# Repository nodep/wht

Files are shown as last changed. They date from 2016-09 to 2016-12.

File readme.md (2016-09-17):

This project implements a 3 axis wireless gyro. The hardware consists of two parts: a tracker with sensors and a USB dongle.

The data received from the sensors can be passed to the PC through a USB dongle which enumerates as a joystick and mouse.

The tracker contains these ICs:

- Nordic Semiconductor nRF24LE1 MCU (8-bit 8051)
- InvenSense MPU-6050 (or MPU-9150) IMU (gyro and accelerometer)
- Asahi Kasei AK8975 (magnetometer)

The USB dongle uses a Nordic Semiconductor nRF24LU1+ 2.4GHz and does most of the numerical processing.

There are several variants of the tracker which vary in size and power source. The most practical variant runs off of a single AA battery and has a 3.3V boost regulator (MCP1640). Another variant uses a CR123A lithium battery without a regulator.

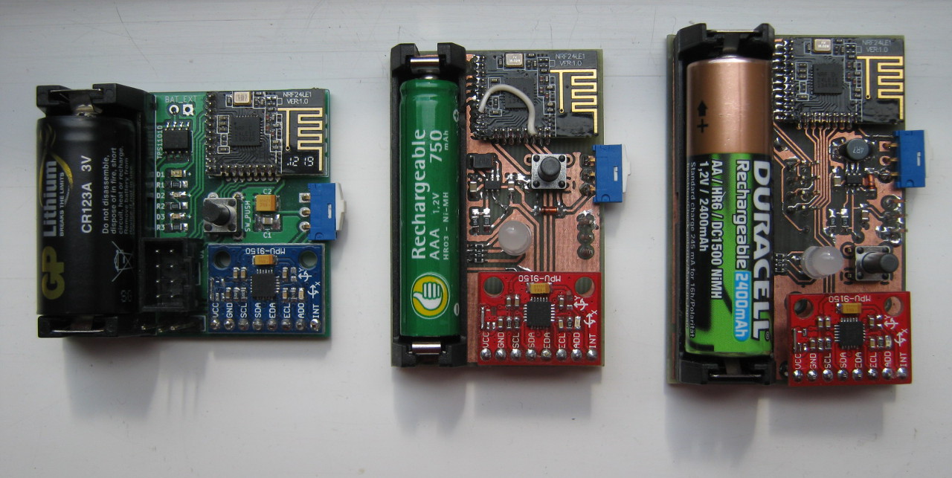
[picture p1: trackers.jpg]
trackers


The tracker is designed around modules (MCU and sensors) which can be easily found on ebay or similar online shops.

The code can be compiled with sdcc (Small Device C Compiler) and flashed to the Nordic nRF chips using nrfburn: https://github.com/nodep/nrfburn

The project contains design files (OpenSCAD and stl) for 3D printed enclosures for the tracker and the dongle.

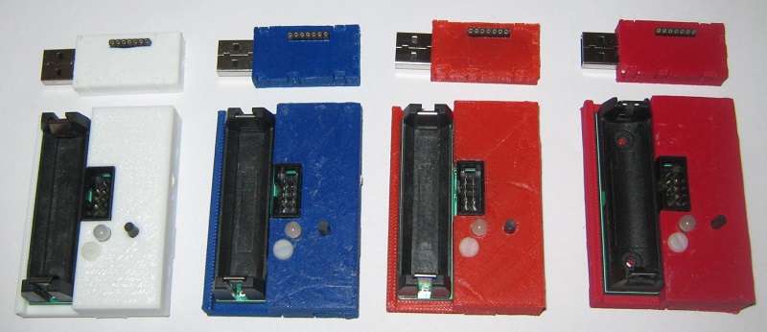
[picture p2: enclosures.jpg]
trackers and dongles in enclosures


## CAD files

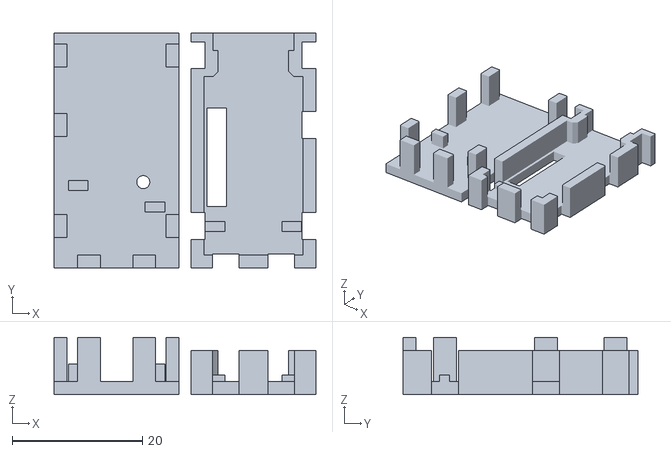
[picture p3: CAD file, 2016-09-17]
enclosure/dongle.stl
40.2 x 36.1 x 8.80

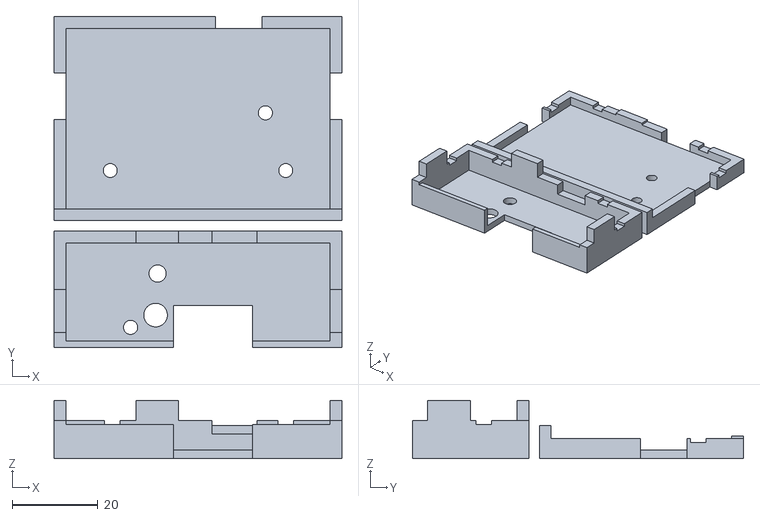
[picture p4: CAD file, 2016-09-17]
enclosure/case_aa.stl
67.1 x 77.2 x 13.6

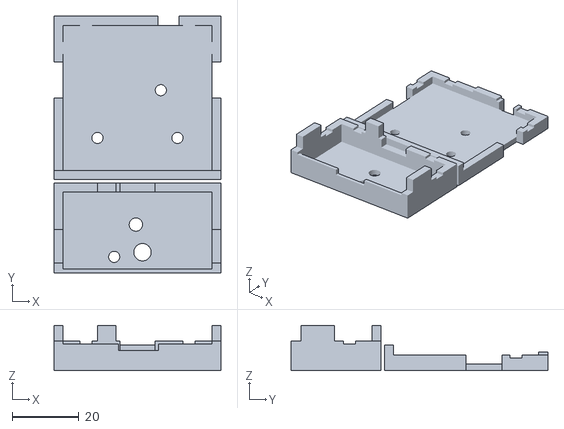
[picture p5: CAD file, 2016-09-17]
enclosure/case_cr123a.stl
50.1 x 77.0 x 13.6

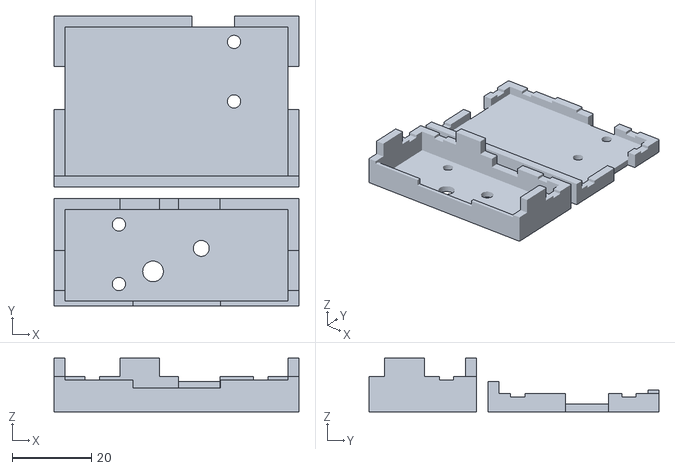
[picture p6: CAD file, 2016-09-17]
enclosure/case_aaa.stl
61.6 x 73.0 x 13.6

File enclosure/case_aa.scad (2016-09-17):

$fn = 80;

include <pcb_aa.scad>

wall_thick_sides = 2.75;
wall_thick_topnbot = 2;
pcb_wiggle = 0.3;
down_room = 1.8;
up_room = 6;
batt_holder_width = 17.4;

switch_x1 = 17;
switch_x2 = 27;
switch_z = 2.1;
switch_wiggle = 0.5;

originx = 35.078;
originy = 104.6385;

module mounting_holes()
{
	// mounting holes
	translate([wall_thick_sides + pcb_wiggle, wall_thick_sides + pcb_wiggle, 0])
	{
		// battery holder holes
		translate([45.128 - originx, originy - 95.9885, -0.1]) cylinder(r = 1.62, h = 25);
		translate([86.028 - originx, originy - 95.9885, -0.1]) cylinder(r = 1.62, h = 25);
		
		// screw hole(s)
		
		// MPU-9150
		//translate([49.20568, 38.84374, -0.1]) cylinder(r = 1.67, h = 25);
		//translate([49.20568, 23.84504, -0.1]) cylinder(r = 1.67, h = 25);
		
		// MPU-6050 + HMC5883L
		translate([82.083 - originx - 0.8, originy - 82.5435, -0.1]) cylinder(r = 1.65, h = 25);
	}
}

module hollow()
{
	translate([wall_thick_sides, wall_thick_sides, wall_thick_topnbot])
		cube([pcbx + pcb_wiggle*2, pcby + pcb_wiggle*2, up_room + down_room + pcb_thick]);
}

module cpegs(wiggle = 0)
{
	cpeg_width = 10;

	cpegy = 24;

	cpeg_height = wall_thick_topnbot + pcb_thick/2 + down_room;

	translate([0, cpegy - wiggle/2, 0])
		cube([wall_thick_sides, cpeg_width + wiggle, cpeg_height]);

	translate([wall_thick_sides + pcbx + pcb_wiggle*2, cpegy - wiggle/2, 0])
		cube([wall_thick_sides, cpeg_width + wiggle, cpeg_height]);

	cpegx = 35;

	translate([wall_thick_sides + pcb_wiggle + cpegx - wiggle/2, wall_thick_sides + pcby + pcb_wiggle*2, 0])
		cube([cpeg_width + wiggle, wall_thick_sides, cpeg_height]);
}

module bottom()
{
	difference()
	{
		union()
		{
			// lower floor
			cube([pcbx + pcb_wiggle*2 + wall_thick_sides*2, pcby + pcb_wiggle*2 + wall_thick_sides*2, pcb_thick/2 + down_room + wall_thick_topnbot]);

			// horizontal battery wall
			translate([0, 0, pcb_thick/2 + down_room + wall_thick_topnbot])
				cube([pcbx + pcb_wiggle*2 + wall_thick_sides*2, wall_thick_sides, 3]);

			// the switch
			translate([wall_thick_sides + pcb_wiggle + switch_x1, wall_thick_sides + pcby + pcb_wiggle*2, pcb_thick/2 + down_room + wall_thick_topnbot])
				cube([switch_x2 - switch_x1, wall_thick_sides, pcb_thick/2 - 0.3]);
		}

		cpegs(0.8);

		hollow();

		translate([wall_thick_sides + pcb_wiggle, wall_thick_sides + pcb_wiggle, wall_thick_topnbot])
			pcb(do_drills = 0, pcb_zoffset = down_room, peg_wiggle = pcb_wiggle, peg_length = wall_thick_sides + 0.5);

		mounting_holes();
	}
}

module top()
{
	// MPU-9150
	//ledx = 76.48;
	//ledy = 80.2545;

	// MPU-6050 or HMC5883L
	ledx = 75.464;
	ledy = 79.683;

	flashx = 62.078 - originx;
	flashy = originy - 82.1385;

	flash_sizex = 18.4;
	flash_sizey = 9.4;

	buttonx = 75;
	buttony = 70;

	inner_wall_thick = 1.5;

	difference()
	{
		translate([0, wall_thick_sides + pcb_wiggle + batt_holder_width, wall_thick_topnbot + pcb_thick/2 + down_room])
			cube([wall_thick_sides*2 + pcbx + pcb_wiggle*2, pcby - batt_holder_width + wall_thick_sides + pcb_wiggle, up_room + pcb_thick/2 + wall_thick_topnbot]);

		// the PCB pegs
		translate([wall_thick_sides + pcb_wiggle, wall_thick_sides + pcb_wiggle, wall_thick_topnbot])
			pcb(do_drills = 0, pcb_zoffset = down_room, peg_wiggle = pcb_wiggle, peg_length = wall_thick_sides + 0.5);

		// the switch
		translate([wall_thick_sides + pcb_wiggle + switch_x1 - switch_wiggle/2, wall_thick_sides + pcb_wiggle*2 + pcby, wall_thick_topnbot + down_room + pcb_thick/2])
			cube([switch_x2 - switch_x1 + switch_wiggle, wall_thick_sides + pcb_wiggle + 0.2, pcb_thick/2 + switch_z + 0.2]);

		hollow();

		mounting_holes();

		// the led hole
		translate([ledx - originx + wall_thick_sides + pcb_wiggle, originy - ledy + wall_thick_sides + pcb_wiggle, wall_thick_topnbot + down_room + pcb_thick + up_room - 0.05])
			cylinder(r = 2.75, h = wall_thick_topnbot + 0.1);

		// the flash connector hole
		translate([flashx - flash_sizex/2 + wall_thick_sides + pcb_wiggle, flashy - flash_sizey/2 + wall_thick_sides + pcb_wiggle - 1, wall_thick_topnbot + down_room + pcb_thick + up_room - 0.05])
			cube([flash_sizex, flash_sizey + 1, wall_thick_topnbot + 0.1]);

		// the recenter button
		translate([buttonx - originx + wall_thick_sides + pcb_wiggle, originy - buttony + wall_thick_sides + pcb_wiggle, 0])
			cylinder(r = 2, h = 20);
	}

	// the inner wall
	translate([wall_thick_sides, wall_thick_sides + pcb_wiggle + batt_holder_width, wall_thick_topnbot + pcb_thick + down_room])
		cube([flashx - flash_sizex/2 + pcb_wiggle, inner_wall_thick, up_room]);

	translate([wall_thick_sides + pcb_wiggle + flashx + flash_sizex/2, wall_thick_sides + pcb_wiggle + batt_holder_width, wall_thick_topnbot + pcb_thick + down_room])
		cube([pcbx - flashx - flash_sizex/2 + pcb_wiggle, inner_wall_thick, up_room]);

	cpegs();
}

bottom();

rotate([0, 180, 0])
	translate([-(wall_thick_sides*2 + pcbx + pcb_wiggle*2), -50, -(wall_thick_topnbot*2 + down_room + up_room + pcb_thick)])
	top();

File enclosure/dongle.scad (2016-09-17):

$fn = 100;

pcbd_thick = 1.1;

// the main part of the dongle PCB
pcbw_x = 14.8;
pcbw_y = 27;

// the neck part of the dongle PCB
pcbn_x = 10.5;
pcbn_y = 4.2;

pcb_zoffset = 0.3;

// USB plug
plug_x = 12.15;
plug_y = 14.8;
plug_z = 5;

// USB plug neck
plugn_x = 9.6;
plugn_y = pcbn_y;
plugn_z = plug_z/2 + pcb_zoffset;

module flash_connector(flash_wigglex = 0, flash_wiggley = 0)
{
	// flashing connector
	flash_sizex = 2.4 + flash_wigglex;
	flash_sizey = 14.6 + flash_wiggley;
	flash_sizez = 5.6 - pcbd_thick;
	flash_posx = 0.6 - flash_wigglex/2;
	flash_posy = 22.1 - flash_sizey + flash_wiggley/2;

	translate([-pcbw_x/2 + flash_posx, flash_posy, -pcbd_thick/2 - flash_sizez])
		cube([flash_sizex, flash_sizey, flash_sizez]);
}

module dongle()
{
	// PCB main PCB
	translate([-pcbw_x/2, 0, -pcbd_thick/2])
		cube([pcbw_x, pcbw_y, pcbd_thick]);

	// PCB neck
	translate([-pcbn_x/2, pcbw_y, -pcbd_thick/2])
		cube([pcbn_x, pcbn_y, pcbd_thick]);

	// USB plug
	translate([-plug_x/2, pcbw_y+pcbn_y, -plug_z/2 + pcbd_thick/2 + pcb_zoffset])
		cube([plug_x, plug_y, plug_z]);
	translate([-plugn_x/2, pcbw_y, pcbd_thick/2])
		cube([plugn_x, plugn_y, plugn_z]);

	flash_connector();
}

pcb_wiggle = 0.4;
wall_thick = 2;

inside_x = pcbw_x + pcb_wiggle;
inside_y = pcbw_y + pcb_wiggle;
inside_z = 4.4 + pcb_wiggle;

module pegs(peg_wiggle = 0.0, thick_wiggle = 0.0)
{
	peg_length = 3.5;
	peg_height = inside_z + wall_thick + peg_wiggle;
	peg_z = -inside_z/2 - wall_thick + pcbd_thick/2 + pcb_zoffset;

	peg_height_flash = inside_z + peg_wiggle;
	peg_z_flash = -inside_z/2 + pcbd_thick/2 + pcb_zoffset;

	// pegs across the length
	peg1_y = 2.5;
	peg2_y = 18;
	peg3_y = 28.7;

	translate([inside_x/2 - thick_wiggle/2, peg1_y - peg_wiggle/2, peg_z])
		cube([wall_thick + thick_wiggle, peg_length + peg_wiggle, peg_height]);

	translate([inside_x/2 - thick_wiggle/2, peg2_y - peg_wiggle/2, peg_z])
		cube([wall_thick + thick_wiggle, peg_length + peg_wiggle, peg_height]);

	translate([inside_x/2 - thick_wiggle/2, peg3_y - peg_wiggle/2, peg_z])
		cube([wall_thick + thick_wiggle, peg_length + peg_wiggle, peg_height]);

	translate([-inside_x/2 - wall_thick - thick_wiggle/2, peg1_y - peg_wiggle/2, peg_z])
		cube([wall_thick + thick_wiggle, peg_length + peg_wiggle, peg_height]);

	translate([-inside_x/2 - wall_thick - thick_wiggle/2, peg3_y - peg_wiggle/2, peg_z])
		cube([wall_thick + thick_wiggle, peg_length + peg_wiggle, peg_height]);

	// pegs across the width
	peg4_x = 2.5;

	translate([peg4_x - peg_wiggle/2, -wall_thick - pcb_wiggle/2 - thick_wiggle/2, peg_z])
		cube([peg_length + peg_wiggle, wall_thick + thick_wiggle, peg_height]);
		
	translate([-peg4_x - peg_length - peg_wiggle/2, -wall_thick - pcb_wiggle/2 - thick_wiggle/2, peg_z])
		cube([peg_length + peg_wiggle, wall_thick + thick_wiggle, peg_height]);
}

case_x = inside_x + wall_thick*2;
case_y = inside_y + wall_thick + pcbn_y + 2.5;
case_z = inside_z + wall_thick*2;

module case_top()
{
	// the LED position
	led_x = 3.3;
	led_y = 11;

	difference()
	{
		translate([-case_x/2, -(pcb_wiggle/2 + wall_thick), inside_z/2 + pcbd_thick/2 + pcb_zoffset])
			cube([case_x, case_y, wall_thick]);

		// the LED hole
		translate([-pcbw_x/2 + led_x, led_y, inside_z/2 + pcbd_thick/2 + pcb_zoffset - 0.1])
			cylinder(wall_thick + 0.2, 1, 1);
	}

	// the stand-offs
	stdoff_thick = 1.5;
	stdoff_height = inside_z/2 + pcb_zoffset;
	stdoff_len = 3;
	stdoff_z = inside_z/2 + pcbd_thick/2 + pcb_zoffset - stdoff_height;

	stdoff1_y = 10.3;
	translate([pcbw_x/2 - stdoff_len, stdoff1_y + pcb_wiggle/2 - stdoff_thick/2, stdoff_z])
		cube([stdoff_len, stdoff_thick, stdoff_height]);

	stdoff3_y = 7;
	translate([-pcbw_x/2, stdoff3_y + pcb_wiggle/2 - stdoff_thick/2, stdoff_z])
		cube([stdoff_len, stdoff_thick, stdoff_height]);

	pegs();
}

module case_bottom(pw = 0.0, ptw = 0.0)
{
	difference()
	{
		translate([-case_x/2, -(pcb_wiggle/2 + wall_thick), -case_z/2 + pcbd_thick/2 + pcb_zoffset])
			cube([case_x, case_y, case_z - wall_thick]);

		translate([-inside_x/2, -pcb_wiggle/2, -inside_z/2 + pcbd_thick/2 + pcb_zoffset])
			cube([inside_x, inside_y, inside_z + 0.1]);

		// wiggle room for the flash connector
		flash_connector(flash_wigglex = 0.6, flash_wiggley = 0.5);

		neck_wigglex = 0.3;
		neck_wigglez = 0.2;

		// PCB and USB neck
		translate([-pcbn_x/2 - neck_wigglex/2, pcbw_y, -plug_z/2 + pcbd_thick/2 + pcb_wiggle])
			cube([pcbn_x + neck_wigglex, pcbn_y, plug_z]);

		// cut-offs for the round edge of the pcb neck
		cutoff = 0.8;
		translate([-pcbn_x/2 - neck_wigglex/2, pcbw_y + pcb_wiggle/2, -plug_z/2 + pcbd_thick/2 + pcb_wiggle])
			linear_extrude(height = plug_z)
				polygon([[0, 0], [-cutoff, 0], [0, cutoff]]);

		translate([pcbn_x/2 + neck_wigglex/2, pcbw_y + pcb_wiggle/2, -plug_z/2 + pcbd_thick/2 + pcb_wiggle])
			linear_extrude(height = plug_z)
				polygon([[0, 0], [cutoff, 0], [0, cutoff]]);
				
		// USB plug
		translate([-plug_x/2 - neck_wigglex/2, pcbw_y + pcbn_y, -plug_z/2 + pcbd_thick/2 + pcb_wiggle])
			cube([plug_x + neck_wigglex, plug_y, plug_z]);

		pegs(peg_wiggle = pw, thick_wiggle = ptw);
	}

	// the stand-offs
	stdoff_thick = 1.5;
	stdoff_height = inside_z/2 - pcb_zoffset - pcbd_thick;
	stdoff_len = 3;

	stdoff1_y = 4;
	translate([pcbw_x/2 - stdoff_len, stdoff1_y + pcb_wiggle/2 - stdoff_thick/2, -pcbd_thick/2 - stdoff_height])
		cube([stdoff_len, stdoff_thick, stdoff_height]);

	translate([-pcbw_x/2, stdoff1_y + pcb_wiggle/2 - stdoff_thick/2, -pcbd_thick/2 - stdoff_height])
		cube([stdoff_len, stdoff_thick, stdoff_height]);
}

translate([0, 0, case_z/2 - pcbd_thick/2 - pcb_zoffset])
	case_bottom(pw = 0.6, ptw = 0.3);

rotate([0, 180, 0])
	translate([21, 0, -case_z/2 - pcbd_thick/2 - pcb_zoffset])
	case_top();

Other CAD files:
enclosure/case_aaa.scad
enclosure/case_cr123a.scad
enclosure/pcb_aa.scad
enclosure/pcb_aaa.scad
enclosure/pcb_cr123a.scad

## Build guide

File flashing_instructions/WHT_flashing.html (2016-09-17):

# Wireless Head Tracker flashing instructions

## Flashing background information

The WHT consists of two separate devices: the first device is the tracker which contains the motion sensor and a microcontroller (just a fancy word for a low power computer) with a 2.4GHz radio transmitter and receiver. The second device is a USB dongle, another microcontroller and another 2.4GHz radio. This USB dongle receives the movement sensor information from the tracker, then processes it and sends it over the USB port to the PC.
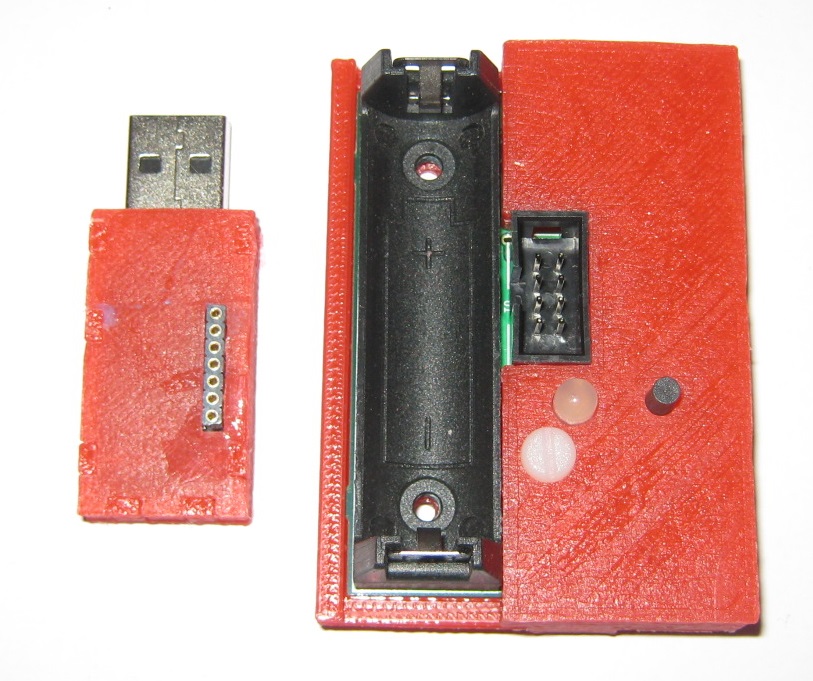
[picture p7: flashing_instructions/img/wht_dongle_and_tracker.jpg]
dongle and tracker


As I've mentioned, the microcontrollers on these two devices are essentially small computers and they contain a little bit of flash memory (16 kilobytes each). This flash memory stores the software these small computers are running. Software running on microcontrollers is often called firmware but in essence it is not much different from software running on your PC or smartphone. And just like any software, the firmware on the tracker and the dongle can be updated to fix bugs or add new features. This update process is called firmware flashing.

In order to flash the two devices, you need to have another device called a flash programmer. It connects to the PC though a USB cable, and to the tracker through a cable, or to the dongle by directly plugging it into the programmer. The programmer receives commands and data from the PC, then sends these commands to the microcontroller on the tracker or dongle which overwrites their flash memory.

The flash programmer with the tracker flashing cable:
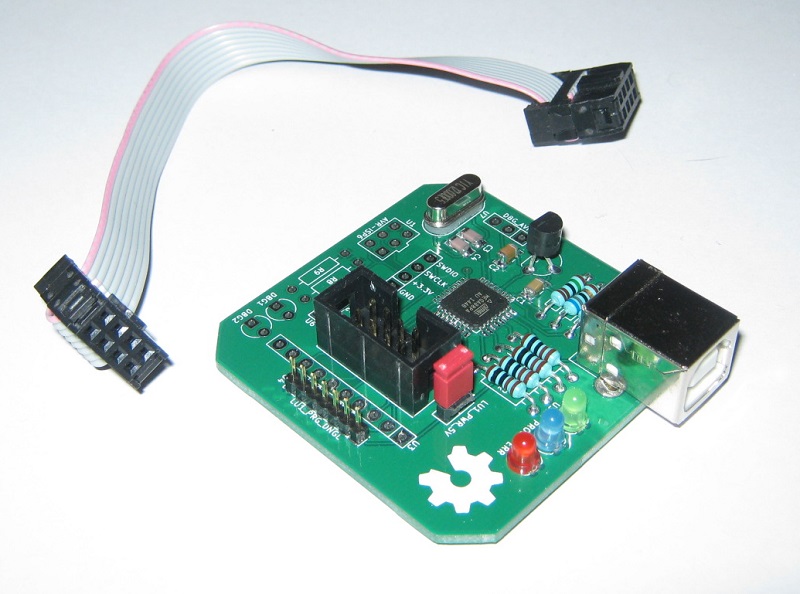
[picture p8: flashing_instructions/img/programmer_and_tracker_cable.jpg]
flash programmer


The flash programmer does not need drivers, but you will need to wait a few minutes after plugging in the programmer for the first time for Windows to figure that out.

## The necessary software

The PC software needed to communicate with the flash programmer, the flash images for the dongle and tracker and the WHT configuration program are all contained in the WHT software package. You will have received it together with this document.

The WHT package has three subfolders:

- config - the configuration and calibration program.
- flashing_instructions - contains these instructions.
- flash - contains the files necessary for the flashing process.

The flash folder contains these files:

- nrfburn.exe - the software which communicates with the flash programmer
- flash_dongle.bat - the windows batch file which calls nrfburn.exe with the required parameters to flash the dongle
- flash_tracker.bat - the windows batch file which calls nrfburn.exe with the required parameters to flash the tracker
- tracker.hex - the tracker flash image
- whtdngl.hex - the dongle flash image

## Tracker flashing details

- Remove the battery from the tracker
- Remove the flash programmer from USB (if it is plugged in)
- If the tracker or the dongle is connected to the flash programmer - remove them
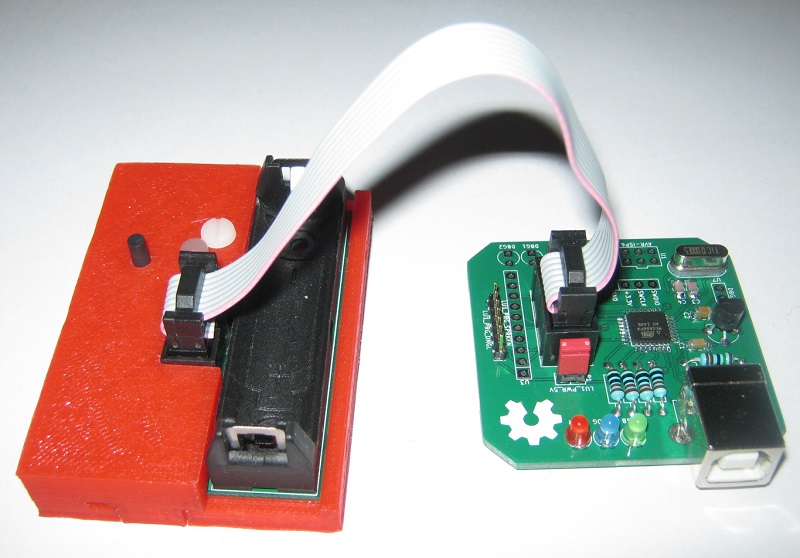
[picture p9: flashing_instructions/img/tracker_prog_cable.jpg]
flasher and tracker
- Plug one end of the flashing cable into the tracker and other into the flash programmer 
- Plug the programmer with the tracker attached into USB. If this is the first time you plugged in the programmer into your PC's USB port, wait a minute or two for Windows to recognize the programmer. You will get a "This device is now ready" message from Windows.
- Go to the folder where you unpacked the WHT software and in the flash subfolder double-click the flash_tracker batch file. The flashing process should take about 6 seconds.
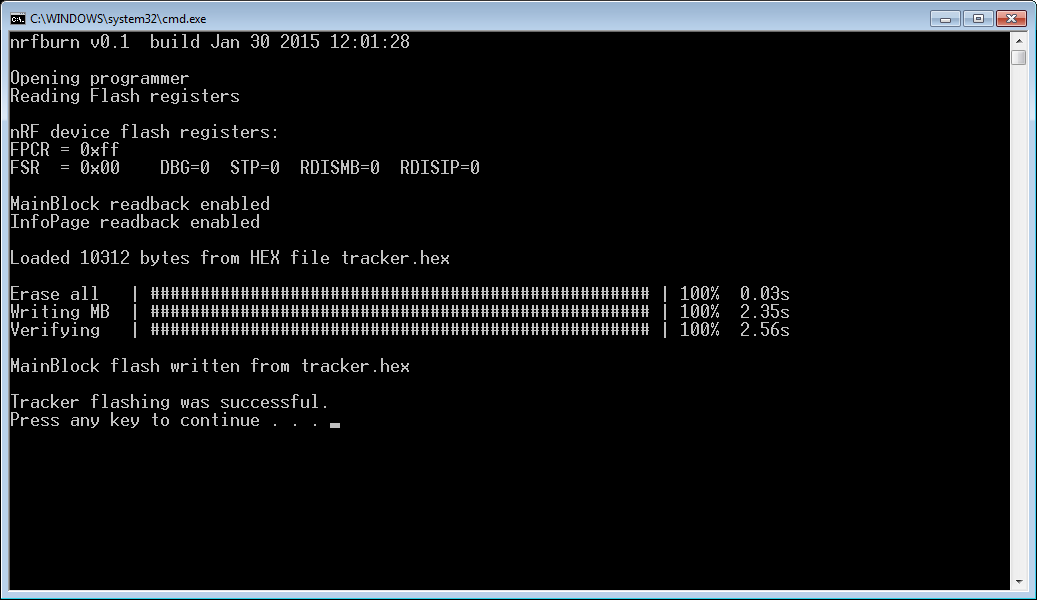
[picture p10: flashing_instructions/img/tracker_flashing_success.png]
tracker flashing
- If the flashing is successful you will see this message in the window: 
- Note that the number of bytes loaded will be different than shown on this image.
- Unplug the flash programmer from USB.
- Remove the programming cable from the programmer and the tracker.
- Put the battery back into the tracker.
- You're done!

## Dongle flashing details

- Remove the flash programmer from USB (if it is plugged in)
- If the tracker or the dongle is connected to the flash programmer - remove them
- Remove the tracker or from the programmer if it is connected to it
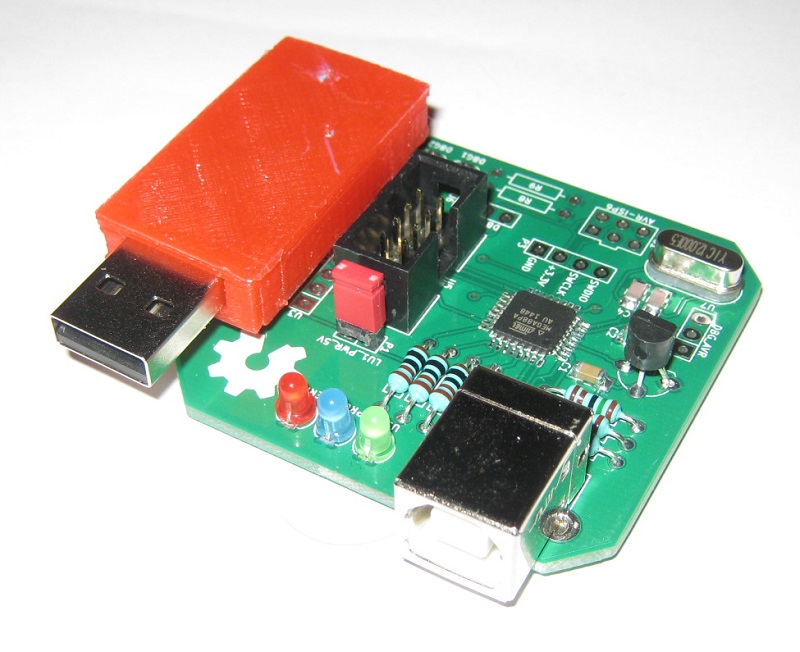
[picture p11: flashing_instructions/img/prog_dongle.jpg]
flashing dongle
- Plug the dongle directly into the programmer's row of pins labelled "LU1+ generic". Make sure that every pin in the programmer is connected to every slot in the dongle. 
- Plug the programmer with the dongle attached into USB. If this is the first time you plugged in the programmer into your PCs USB port, wait a minute or two for Windows to recognize the programmer. You will get a "This device is now ready" message from Windows.
- Go to the folder where you unpacked the WHT software package and run the flash_dongle batch file. The flashing process should take about 6 seconds.
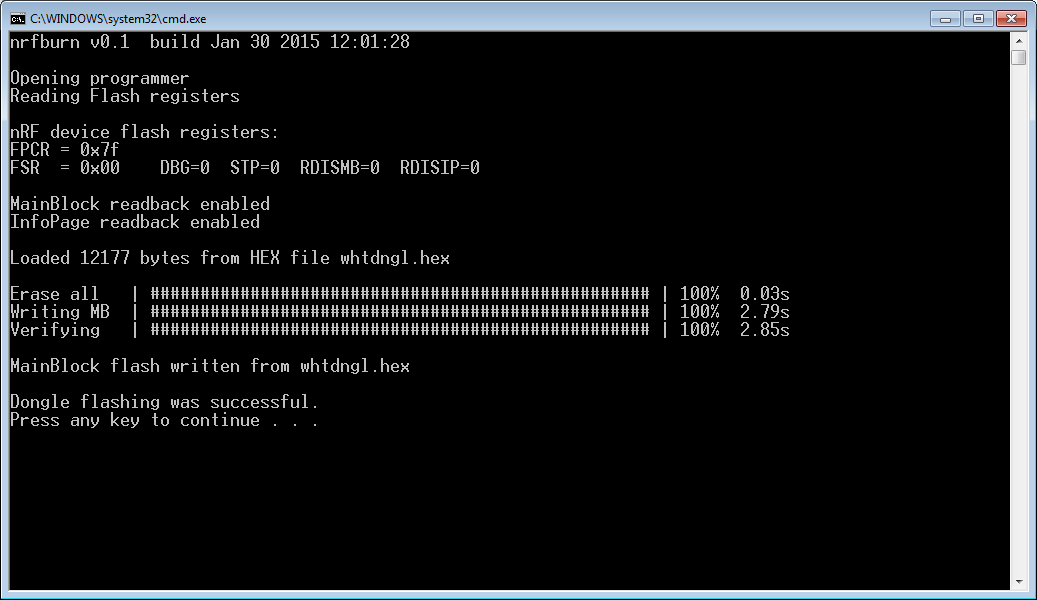
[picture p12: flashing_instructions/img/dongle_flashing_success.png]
dongle flashing
- If the flashing is successful you will see this message in the window: 
- Note that the number of bytes loaded will be different than shown on this image.
- Remove the programmer with the dongle from USB
- Remove the USB dongle from the programmer
- You're done!

After the dongle and tracker have been flashed you will need to recalibrate and reconfigure the devices with the WHTConfig.exe program. You can find the instructions in the video below.

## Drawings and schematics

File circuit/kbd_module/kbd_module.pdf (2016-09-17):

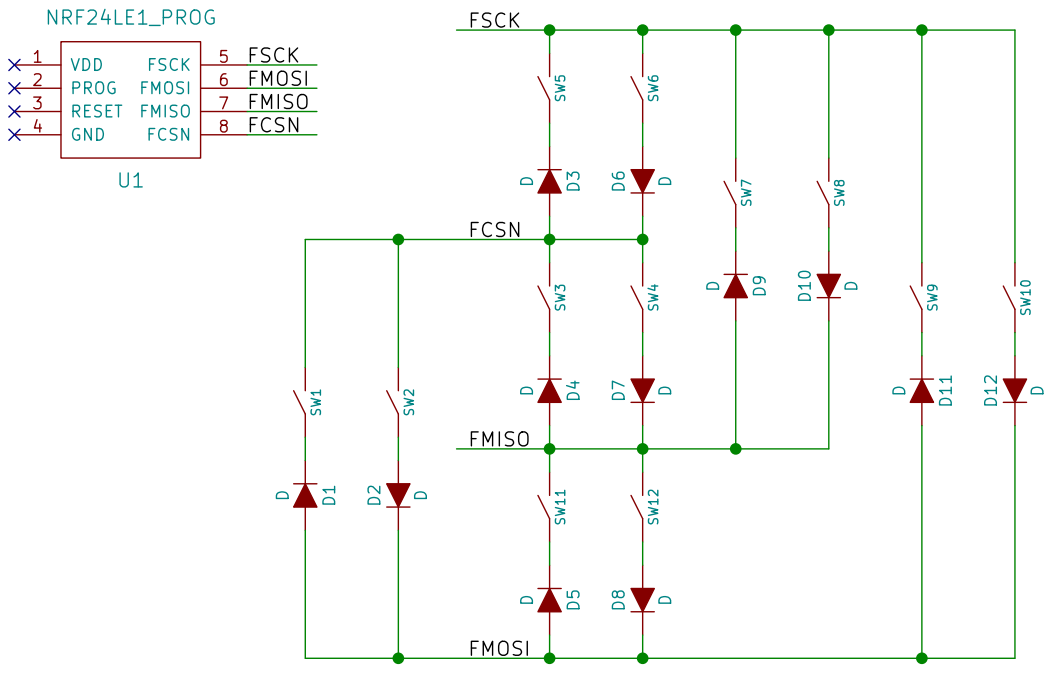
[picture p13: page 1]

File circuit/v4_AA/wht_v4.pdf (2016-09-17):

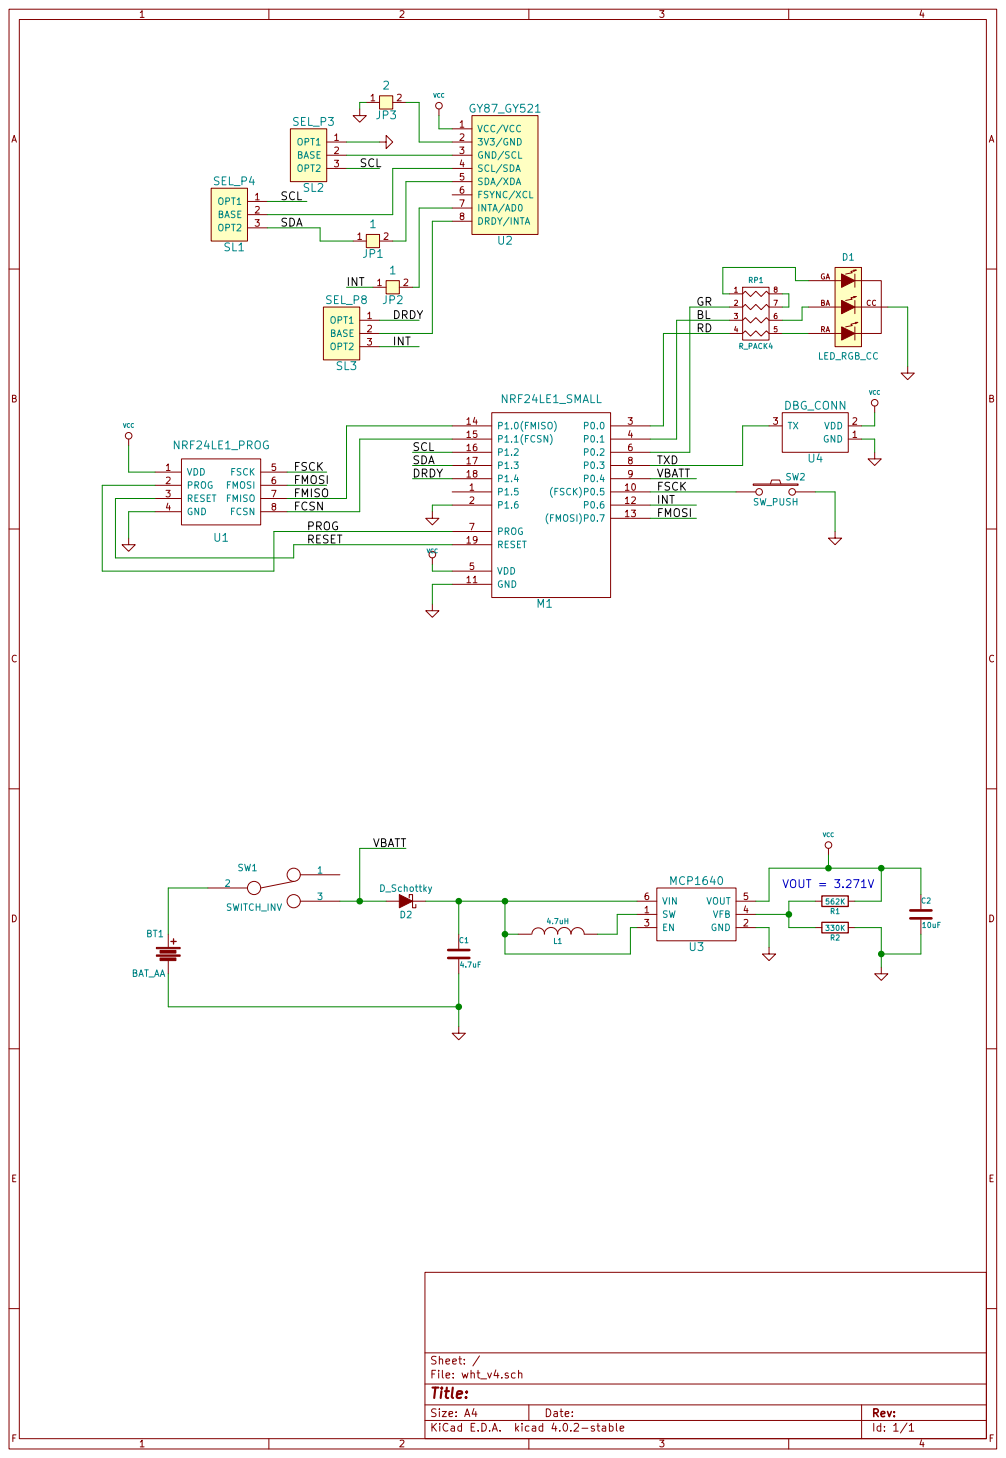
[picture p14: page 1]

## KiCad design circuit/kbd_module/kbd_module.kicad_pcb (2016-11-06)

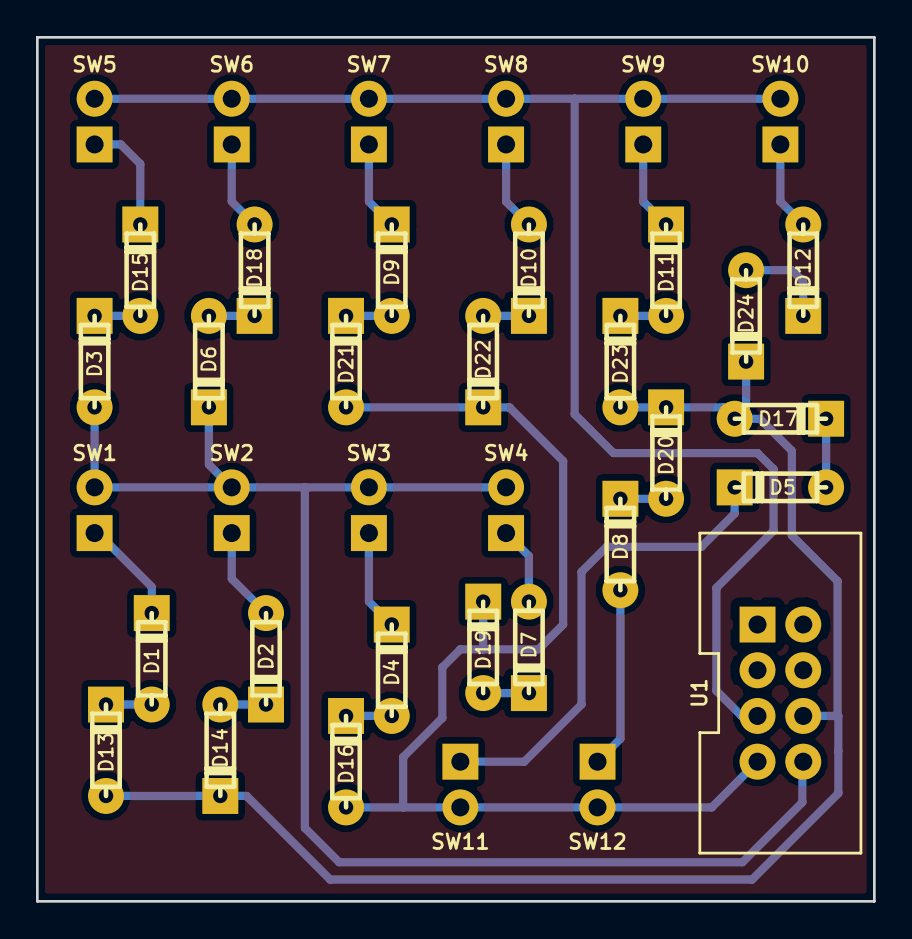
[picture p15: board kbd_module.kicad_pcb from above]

Board: 2 copper layers, 46.5 x 48.0 mm, 37 parts (0 on the bottom side), 28 nets.

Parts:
D1, D2, D3, D4, D5, D6, D7, D8, D9, D10, D11, D12, D13, D14, D15, D16, D17, D18, D19, D20, D21, D22, D23, D24: 1n4148; SOD27_RM5_5
SW1, SW2, SW3, SW4, SW5, SW6, SW7, SW8, SW9, SW10, SW11, SW12: SW_SIMPLE; ExtSwitch
U1: NRF24LE1_PROG; NRF_ICSP_RibbonCable

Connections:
/FCSN: D3.2, D6.1, SW1.2, SW2.2, SW3.2, SW4.2, U1.8
/FMISO: D16.2, D19.1, D21.2, D22.1, SW11.2, SW12.2, U1.7
/FMOSI: D13.2, D14.1, D17.2, D20.1, D23.2, D24.1, U1.6
/FSCK: SW5.2, SW6.2, SW7.2, SW8.2, SW9.2, SW10.2, U1.5
unnamed: D1.1, SW1.1
unnamed: D1.2, D13.1
unnamed: D2.2, SW2.1
unnamed: D4.1, SW3.1
unnamed: D5.1, SW11.1
unnamed: D7.2, SW4.1
unnamed: D8.2, SW12.1
unnamed: D9.1, SW7.1
unnamed: D10.1, D22.2
unnamed: D10.2, SW8.1
unnamed: D11.1, SW9.1
unnamed: D11.2, D23.1
unnamed: D12.1, D24.2
unnamed: D12.2, SW10.1
unnamed: D2.1, D14.2
unnamed: D15.1, SW5.1
unnamed: D3.1, D15.2
unnamed: D4.2, D16.1
unnamed: D5.2, D17.1
unnamed: D6.2, D18.1
unnamed: D18.2, SW6.1
unnamed: D7.1, D19.2
unnamed: D8.1, D20.2
unnamed: D9.2, D21.1

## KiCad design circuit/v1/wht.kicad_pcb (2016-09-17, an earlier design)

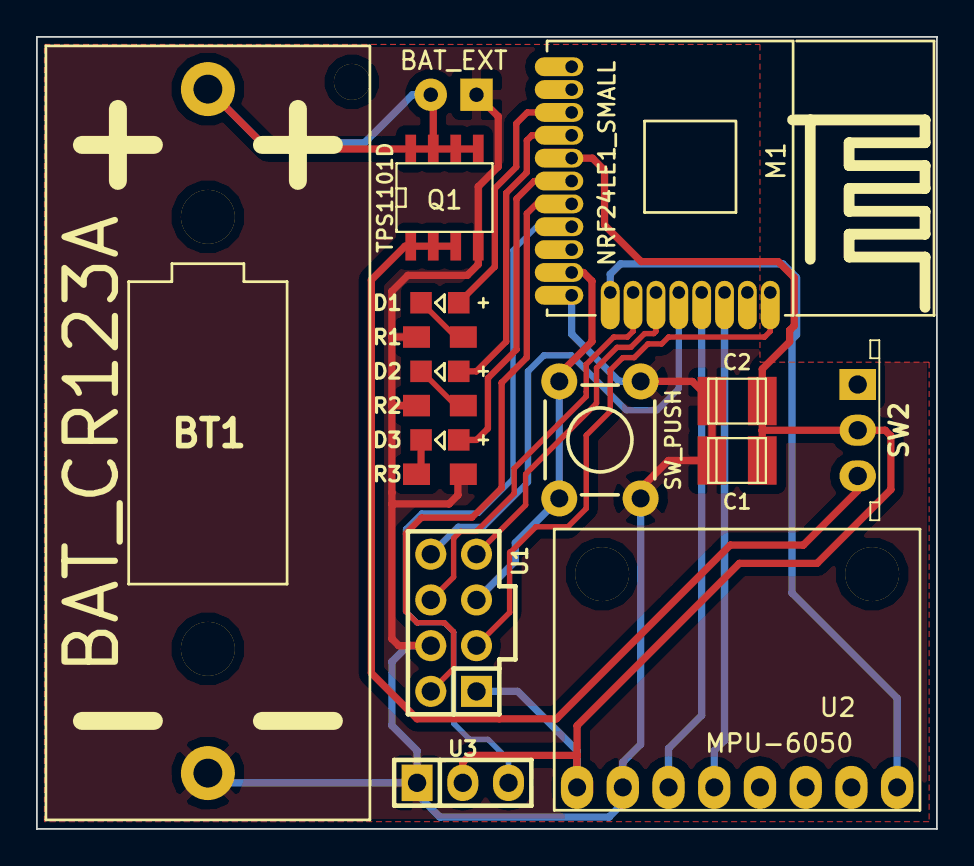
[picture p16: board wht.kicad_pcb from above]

Board: 2 copper layers, 50.0 x 44.0 mm, 17 parts (0 on the bottom side), 20 nets.

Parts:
BT1: BAT_CR123A; CR123
BT2: BAT_EXT; BATTERY_EXT
C1: C; c_1210
C2: CP1; c_1210
D1, D2, D3: LED; LED-0805
M1: NRF24LE1_SMALL
Q1: TPS1101D; SOIC-8_N
R1, R2, R3: R; Resistor_SMD0805_HandSoldering
SW1: SW_PUSH; TACTILE-PTH
SW2: SWITCH_INV; ESP2010_switch
U1: NRF24LE1_PROG; Pin_Header_Straight_2x04
U2: MPU-6050; MPU6050
U3: UART; Pin_Header_Straight_1x03

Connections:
/FCSN: M1.15, U1.8
/FMISO: M1.14, U1.7
/FMOSI: M1.13, U1.6
/FSCK: M1.10, SW1.1, U1.5
/PROG: M1.7, U1.2
/RESET: M1.19, U1.3
/SCL: M1.16, U2.3
/SDA: M1.17, U2.4
GND: BT1.2, BT2.2, C1.2, C2.2, M1.11, Q1.4, R1.1, R2.1, R3.1, SW1.2, U1.4, U2.2, U3.1
unnamed: BT1.1, BT2.1, Q1.5, Q1.6, Q1.7, Q1.8
unnamed: D1.1, M1.3
unnamed: D1.2, R1.2
unnamed: D2.1, M1.4
unnamed: D2.2, R2.2
unnamed: D3.1, M1.6
unnamed: D3.2, R3.2
unnamed: M1.8, U3.3
unnamed: M1.12, U2.8
unnamed: Q1.1, Q1.2, Q1.3, SW2.3
VCC: C1.1, C2.1, M1.5, SW2.2, U1.1, U2.1, U3.2

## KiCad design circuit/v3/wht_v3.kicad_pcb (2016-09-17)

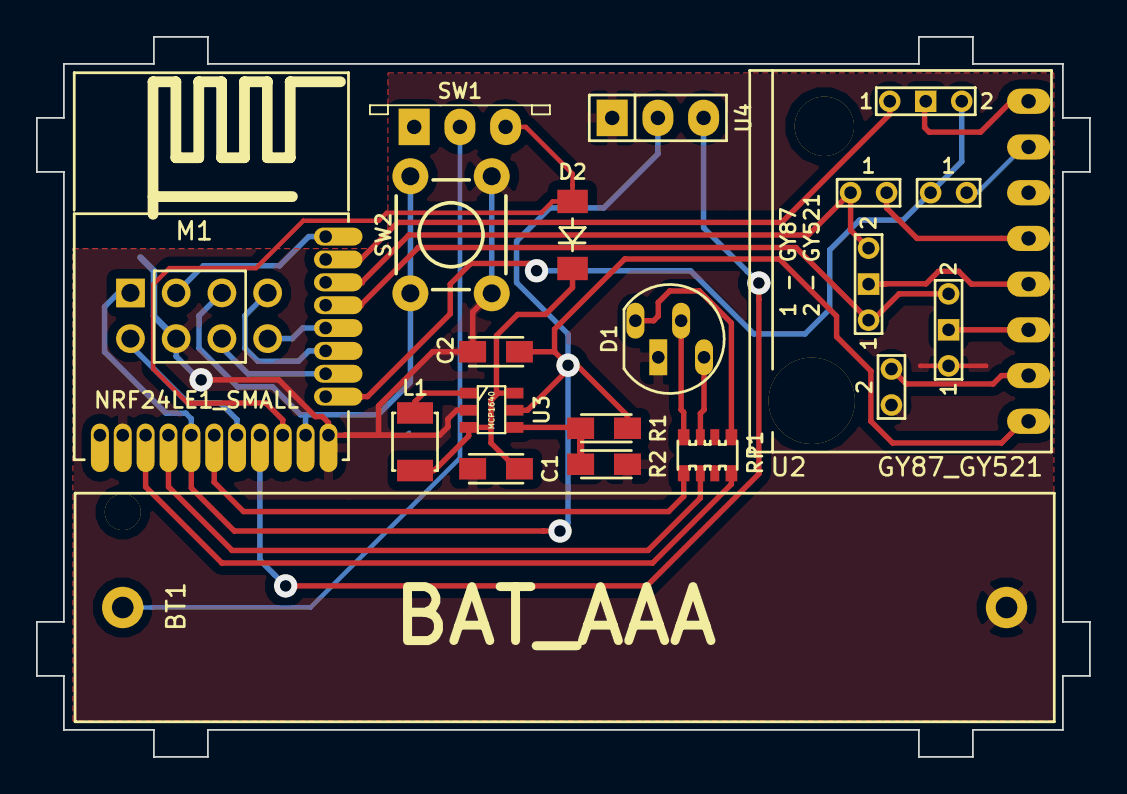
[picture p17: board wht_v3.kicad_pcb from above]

Board: 2 copper layers, 58.5 x 40.0 mm, 22 parts (1 on the bottom side), 30 nets.

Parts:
BT1: BAT_AAA; BATT_HOLDER_AAAx1_KEYSTONE_1021
C1: 4.7uF; Capacitor_SMD0805_HandSoldering
C2: 10uF; Capacitor_SMD0805_HandSoldering
D1: LED_RGB_CC
D2: DIODESCH; Diode-MiniMELF_Handsoldering
JP1, JP2: 1; JumperTHT
JP3: 2; JumperTHT
L1: 4.7uH; INDUCTOR_NLCV25T
M1: NRF24LE1_SMALL
R1: 511K; Resistor_SMD0805_HandSoldering
R2: 348K; Resistor_SMD0805_HandSoldering
RP1: R_PACK4; Resistor_Array_x4_1206
SL1, SL3: SEL_P4; SelectTHT
SL2: SEL_P3; SelectTHT
SW1: SWITCH_INV; ESP2010_switch
SW2: SW_PUSH; TACTILE-PTH
U1: NRF24LE1_PROG; NRF_ICSP_PogoPinsHoles
U2: GY87_GY521
U3: MCP1640; SOT23_6_WHT
U4: DBG_CONN; Pin_Header_Straight_1x03

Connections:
/DRDY: M1.18, SL3.1
/FCSN: M1.15, U1.8
/FMISO: M1.14, U1.7
/FMOSI: M1.13, U1.6
/FSCK: M1.10, SW2.1, U1.5
/GR: M1.6, RP1.1
/INT: JP1.1, M1.12, SL3.3
/PROG: M1.7, U1.2
/RD: M1.3, RP1.4
/RESET: M1.19, U1.3
/SCL: M1.16, SL1.1, SL2.3
/SDA: JP2.1, M1.17, SL1.3
/TXD: M1.8, U4.3
/VBATT: D2.1, M1.9, SW1.3
/YL: M1.4, RP1.2
GND: BT1.2, C1.2, C2.2, D1.CC, JP3.1, M1.2, M1.11, R2.1, SL2.1, SW2.2, U1.4, U3.2, U4.1
unnamed: BT1.1, SW1.2
unnamed: C1.1, D2.2, L1.1, U3.3, U3.6
unnamed: D1.BA, RP1.7
unnamed: D1.GA, RP1.8
unnamed: D1.RA, RP1.5
unnamed: JP1.2, U2.7
unnamed: JP2.2, U2.5
unnamed: JP3.2, U2.2
unnamed: L1.2, U3.1
unnamed: R1.2, R2.2, U3.4
unnamed: SL1.2, U2.4
unnamed: SL2.2, U2.3
unnamed: SL3.2, U2.8
VCC: C2.1, M1.5, R1.1, U1.1, U2.1, U3.5, U4.2

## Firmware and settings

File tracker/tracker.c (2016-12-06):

#include <stdio.h>
#include <stdint.h>
#include <stdbool.h>
#include <string.h>

#include <reg24le1.h>
#include <nrf24l.h>
#include <nrfutils.h>
#include <nrfdbg.h>

#include "i2c.h"
#include "rf_protocol.h"
#include "../dongle/reports.h"
#include "sensors.h"
#include "sleeping.h"
#include "rf_tracker.h"
#include "auto_shutdown.h"
#include "tracker_settings.h"
#include "tracker.h"

uint8_t board_version;

void hw_init()
{
	uint8_t c;

	// check which version of the board we are running on
	P1CON = 0b01010110;		// enable pullup on P1.6
	delay_ms(10);			// wait a little
	board_version = (P16 ? bv_cr123a : bv_nimh);	// read the pin
	P1CON = 0b01110110;		// disable pullup on P1.6

	P0DIR = 0xf0;		// P0.0 P0.1 P0.2 are the LEDs and they are outputs
                        // P0.3 is the UART TX - output
						// P0.5 is the push button - input
						// P0.6 is the MPU interrupt pin - input

	P0CON = 0b01010101;	// turn on the pullup for the recenter button

#if DBG_MODE > 0  &&  KBD_BUTTONS == 0
	// enable FMISO, FMOSI and FCSN as debug output pins
	P1DIR = 0xfc;
	P0DIR = 0x70;
#endif

	// cycle the LEDs
	LED_RED		= 0;
	LED_BLUE	= 0;
	LED_GREEN	= 0;

	for (c = 0; c < 3; ++c)
	{
		LED_RED		= 1;
		delay_ms(40);
		LED_RED		= 0;
		LED_BLUE	= 1;
		delay_ms(40);
		LED_BLUE	= 0;
		LED_GREEN	= 1;
		delay_ms(40);
		LED_GREEN	= 0;
		LED_BLUE	= 1;
		delay_ms(40);
		LED_BLUE	= 0;
	}

	dbgInit();

	dputs("init started");

	LED_BLUE = 1;

	i2c_init();
	mpu_init();

#if AUTO_SHUTDOWN
	init_auto_shutdown();
#endif

	dbgFlush();

	rf_tracker_init();	// init the radio

	init_sleep();		// we need to wake up from RFIRQ

	LED_BLUE = 0;

	dputs("init OK");
}

/*
// This is a test for a new kind of gyro/accel calibration function.
void test_bias(void)
{
	int32_t g[3];
	int32_t a[3];
	int16_t cnt = 0;
	uint8_t more;
	mpu_packet_t pckt;

	while (1)
	{
		if (cnt == 0)
		{
			g[0] = 0;
			g[1] = 0;
			g[2] = 0;

			a[0] = 0;
			a[1] = 0;
			a[2] = 0;
		}

		// wait for the interrupt
		while (MPU_IRQ)
			dbgPoll();
		while (!MPU_IRQ);

		dmp_read_fifo(&pckt, &more);

		a[0] += pckt.accel[0];
		a[1] += pckt.accel[1];
		a[2] += pckt.accel[2];

		g[0] += pckt.gyro[0];
		g[1] += pckt.gyro[1];
		g[2] += pckt.gyro[2];

		if (cnt == 200)
		{
			dprintf("%li   %li   %li\n", a[0] / cnt, a[1] / cnt, a[2] / cnt - 16384);
			cnt = 0;
		} else {
			++cnt;
		}
	}
}
*/

// returns the battery voltage in 10mV units
// for instance: get_battery_voltage() returning 278 equals a voltage of 2.78V
uint16_t get_battery_voltage(void)
{
	uint16_t res;

	// config the ADC

	ADCCON3 = 0b01100000;	// 8 bits, right justify

	ADCCON2 = 0b00000111;	// longest input acquisition window
							// 6us ADC power-down delay

	if (board_version == bv_cr123a)
	{
		ADCCON1 = 0b10111000;	// power up ADC
								// 1/3 VDD
								// internal 1.2V reference
								// starts the conversion
	} else {
		ADCCON1 = 0b10010001;	// power up ADC
								// AIN4
								// reference VDD (3.3V)
								// starts the conversion
	}

	// wait for the conversion to finish
	delay_us(3);	// wait for busy bit to stabilize
	while (ADCCON1 & 0x40)
		;

	res = ADCDATL;

#define MAX_VOLTAGE		327		// 3.27V
//#define MAX_VOLTAGE		298		// 2.98V the prototype

	if (board_version == bv_cr123a)
		res = (res * 72) / 51;
	else
		res = (res * MAX_VOLTAGE) / 255;

	return res;
}

// check for an ACK payload and reacts to it
uint8_t check_ack(void)
{
	uint8_t ack;

	if (rf_tracker_read_ack_payload(&ack, 1))
	{
		if (ack == CMD_CALIBRATE)
		{
			mpu_calibrate_bias();
			return 1;
		} else if (ack == CMD_READ_TRACKER_SETTINGS) {
			rf_tracker_send_message(get_tracker_settings(), sizeof(tracker_settings_t));
		} else if (ack >= CMD_DISABLE_SLEEP  &&  ack <= CMD_SLEEP_LONGEST) {
			const tracker_settings_t __xdata * pSettings = get_tracker_settings();
			if (pSettings->sleep_mode != ack)
			{
				// save the new settings
				tracker_settings_t new_settings;
				memcpy(&new_settings, pSettings, sizeof(new_settings));
				new_settings.sleep_mode = ack;
				save_tracker_settings(&new_settings);
				
				// reset the sleep state
				init_auto_shutdown();
			}
		}
	}

	return 0;
}

#if KBD_MATRIX

uint16_t scan_kbd_matrix(void)
{
	const uint16_t stab_delay = 150;

	// P05 FSCK
	// P07 FMOSI
	// P10 FMISO
	// P11 FCSN

	uint16_t button_states = 0;

	//
	// P05 output - P07, P10, P11 inputs
	//

	P0DIR = 0b11010111;		// P05 is output (and P03 - TX)
	P1DIR = 0b11111111;		// all inputs

	// pullups
	P0CON = 0b01010111;		// P07
	P1CON = 0b01010000;		// P10
	P1CON = 0b01010001;		// P11

	P05 = 0;		// drive low

	delay_us(stab_delay);

	if (P07 == 0)
		button_states |= 0x00100;	// SW9
	if (P10 == 0)
		button_states |= 0x00040;	// SW7
	if (P11 == 0)
		button_states |= 0x00010;	// SW5

	// pulldowns
	P0CON = 0b00110111;		// P07
	P1CON = 0b00110000;		// P10
	P1CON = 0b00110001;		// P11

	P05 = 1;		// drive high

	delay_us(stab_delay);

	if (P07 == 1)
		button_states |= 0x00200;	// SW10
	if (P10 == 1)
		button_states |= 0x00080;	// SW8
	if (P11 == 1)
		button_states |= 0x00020;	// SW6

	P0CON = 0b01110111;		// P07 disable pull up/down
	
	//
	// P07 output - P10, P11 inputs
	//

	P0DIR = 0b01110111;		// P07 is output (and P03 - TX)
	P1DIR = 0b11111111;		// all inputs

	// pullups
	P1CON = 0b01010000;		// P10
	P1CON = 0b01010001;		// P11

	P07 = 0;		// drive low

	delay_us(stab_delay);

	if (P10 == 0)
		button_states |= 0x00800;	// SW12
	if (P11 == 0)
		button_states |= 0x00002;	// SW2

	// pulldowns
	P1CON = 0b00110000;		// P10
	P1CON = 0b00110001;		// P11

	P07 = 1;		// drive high

	delay_us(stab_delay);

	if (P10 == 1)
		button_states |= 0x00400;	// SW11
	if (P11 == 1)
		button_states |= 0x00001;	// SW1

	P1CON = 0b01110000;		// P10 disable pull up/downs
	
	//
	// P10 output - P11 input
	//

	P0DIR = 0b11110111;		// P03 TX is output
	P1DIR = 0b11111110;		// P10 output, P11 input

	// pullups
	P1CON = 0b01010001;		// P11

	P10 = 0;		// drive low

	delay_us(stab_delay);

	if (P11 == 0)
		button_states |= 0x00008;	// SW4

	// pulldowns
	P1CON = 0b00110001;		// P11

	P10 = 1;		// drive high

	delay_us(stab_delay);

	if (P11 == 1)
		button_states |= 0x00004;	// SW3

	P1CON = 0b00110001;		// P11 disable pull up/downs


	// leave everything the way it was
	P0DIR = 0xf0;		// P0.0 P0.1 P0.2 are the LEDs and they are outputs
                        // P0.3 is the UART TX - output
						// P0.5 is the push button - input
						// P0.6 is the MPU interrupt pin - input
						
	P1DIR = 0xff;		// all inputs

	return button_states;
}

#endif	// KBD_MATRIX


#define LED_PCKT_TOTAL		150
#define LED_PCKT_LED_ON		2

// we send 1 aux packet for every AUX_SEND_EVERY positional packets
#define AUX_SEND_EVERY		50

int main(void)
{
	uint8_t rf_pckt_ok = 0, rf_pckt_lost = 0;
	uint8_t aux_counter = 0;
	uint8_t send_recenter_cnt = 0;

	bool read_result;
	tracker_position_packet_t pos_pckt;
	tracker_aux_packet_t aux_pckt;
	mpu_readings_t mpu_rd;

	pos_pckt.tracker_ver = CURR_PROTOCOL_VER;
	aux_pckt.tracker_ver = CURR_PROTOCOL_VER;
	
	pos_pckt.kbd_buttons = 0;

	hw_init();

	for (;;)
	{
		// Waits for the interrupt from the MPU.
		// Instead of polling, I should put the MCU to sleep and then have it awaken by the MPU.
		// However, I have not succeeded in making the wakeup work reliably.
		// I might try putting the MCU to sleep and then waking it up with a timer...
		while (MPU_IRQ)
			dbgPoll();
		while (!MPU_IRQ)
			;

		// read all the packets in the MPU fifo
		read_result = dmp_read_fifo(&mpu_rd);

		if (read_result)
		{
			aux_pckt.shutdown_counter = check_auto_shutdown(mpu_rd.gyro);

			// set the recenter flag
#if KBD_MATRIX
			pos_pckt.flags = send_recenter_cnt;
			pos_pckt.kbd_buttons |= scan_kbd_matrix();
			
# if DBG_MODE
			{
				uint8_t c;
				uint16_t btn = pos_pckt.kbd_buttons;
				for (c = 0; c < 12; c++)
				{
					if (btn & 1)
						putchar('O');
					else
						putchar('.');
					btn >>= 1;
				}
				dputs("");
			}
# endif
#else
			pos_pckt.flags = (RECENTER_BTN == 0  ||  send_recenter_cnt != 0 ? FLAG_RECENTER : 0);
#endif

			// copy the quaternions
			memcpy(pos_pckt.quat, mpu_rd.quat, sizeof(pos_pckt.quat));

			// add the compass data if we have it
			mpu_read_compass(&mpu_rd);

			// set the magnetometer data
			if (mpu_rd.mag_sensor)
			{
				pos_pckt.flags |= FLAG_MAG_VALID;

				if (mpu_rd.mag_sensor == 2)		// is HMC?
					pos_pckt.flags |= FLAG_MAG_SENSOR;

				memcpy(pos_pckt.mag, mpu_rd.mag, sizeof(pos_pckt.mag));
			}

			// send the position packet
			if (rf_tracker_send_message(&pos_pckt, sizeof(pos_pckt)))
			{
				++rf_pckt_ok;

				send_recenter_cnt = check_ack();
				pos_pckt.kbd_buttons = 0;		// reset the keyboard button states
			} else {
				++rf_pckt_lost;
			}

			// update the LEDs
			if (rf_pckt_lost + rf_pckt_ok == LED_PCKT_TOTAL)
			{
				if (rf_pckt_ok > rf_pckt_lost)
					LED_GREEN = 1;
				else
					LED_RED = 1;

			} else if (rf_pckt_lost + rf_pckt_ok == LED_PCKT_TOTAL + LED_PCKT_LED_ON) {
				LED_RED = 0;
				LED_GREEN = 0;

				rf_pckt_ok = rf_pckt_lost = 0;
			}

			// send the aux packet?
			if (++aux_counter >= AUX_SEND_EVERY)
			{
				aux_pckt.flags = 0;

				aux_pckt.voltage = get_battery_voltage();
				aux_pckt.temperature = mpu_read_temperature();

				// disable the self test stuff for now
				//if (mpu_rd.mag_sensor == 2)
				//{
				//	aux_pckt.flags |= FLAG_MAG_VALID | FLAG_MAG_SENSOR;
				//	hmc_self_test(aux_pckt.mag_self_text);
				//} else if (mpu_rd.mag_sensor == 1) {
				//	aux_pckt.flags |= FLAG_MAG_VALID;
				//	akm_self_test(aux_pckt.mag_self_text);
				//}

				// send the packet and check the ACK
				if (rf_tracker_send_message(&aux_pckt, sizeof(aux_pckt)))
				{
					send_recenter_cnt += check_ack();
					aux_counter = 0;
				}
			}
		}
	}
}

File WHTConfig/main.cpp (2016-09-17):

#include "stdafx.h"
#pragma hdrstop

#pragma comment (lib, "winmm.lib")

#include "resource.h"
#include "../dongle/reports.h"

#include "hid.h"
#include "my_win.h"
#include "my_d3dx.h"
#include "d3d.h"
#include "d3d_objects.h"
#include "mag_calib_dialog.h"
#include "gyro_accel_dialog.h"
#include "custom_curves.h"
#include "raw_input.h"
#include "wht_dongle.h"
#include "wht_dialog.h"

int WINAPI wWinMain(HINSTANCE hInstance, HINSTANCE hPrevInstance, PWSTR pCmdLine, int nCmdShow)
{
	try {
		// load hid.dll and the necessary functions from it
		if (!InitHID())
			return -1;

		// we need to seed the random generator
		// it's used to generate test ellipsoid data
		srand(GetTickCount());

		// the accelerator table
		AcceleratorTable accTbl(IDR_ACCELERATORS);

		// create & show the app window
		WHTDialog mainDlg;
		mainDlg.CreateDlg(IDD_MAIN_DIALOG);

		// enter the message loop
		int i = 0;
		MSG msg;
		do {
			if (mainDlg.GetMagCompDialog().IsValid()  ||  mainDlg.GetCustomCurvesDialog().IsValid())
			{
				// clear all the messages
				while (PeekMessage(&msg, NULL, 0, 0, PM_REMOVE) == TRUE)
				{
					if (TranslateAccelerator(mainDlg.GetMagCompDialog().GetHandle(), accTbl.GetHAccel(), &msg) == 0)
					{
						if (!IsDialogMessage(mainDlg.GetHandle(), &msg)
								&&  !IsDialogMessage(mainDlg.GetMagCompDialog().GetHandle(), &msg))
						{
							TranslateMessage(&msg);
							DispatchMessage(&msg);
						}
					}
				}

				if (mainDlg.GetMagCompDialog().IsValid())
					mainDlg.GetMagCompDialog().Render();

				if (mainDlg.GetCustomCurvesDialog().IsValid())
					mainDlg.GetCustomCurvesDialog().Render();

			} else {

				if (GetMessage(&msg, 0, 0, 0))
				{
					if (!IsDialogMessage(mainDlg.GetHandle(), &msg))
					{
						TranslateMessage(&msg);
						DispatchMessage(&msg);
					}
				}
			}

		} while (msg.message != WM_QUIT);

	} catch (std::wstring& e) {
		MessageBox(0, e.c_str(), L"Exception", MB_OK | MB_ICONERROR);
	}

	return 0;
}

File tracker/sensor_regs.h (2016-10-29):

#ifndef MPU_REGS_H
#define MPU_REGS_H

// MPU-6050 registers excluding the I2C master and external sensors
#define SMPLRT_DIV			0x19		// 25 AKA rate_div
#define CONFIG				0x1A		// 26 AKA LPF
#define GYRO_CONFIG			0x1B		// 27
#define ACCEL_CONFIG		0x1C		// 28
#define ACCEL_CONFIG2		0x1D		// 29
#define FIFO_EN				0x23		// 35
#define I2C_MST_CTRL		0x24		// 36
#define INT_PIN_CFG			0x37		// 55
#define INT_ENABLE			0x38		// 56
#define INT_STATUS			0x3A		// 58
#define ACCEL_XOUT_H		0x3B		// 59
#define ACCEL_XOUT_L		0x3C		// 60
#define ACCEL_YOUT_H		0x3D		// 61
#define ACCEL_YOUT_L		0x3E		// 62
#define ACCEL_ZOUT_H		0x3F		// 63
#define ACCEL_ZOUT_L		0x40		// 64
#define TEMP_OUT_H			0x41		// 65
#define TEMP_OUT_L			0x42		// 66
#define GYOR_XOUT_H			0x43		// 67
#define GYOR_XOUT_L			0x44		// 68
#define GYOR_YOUT_H			0x45		// 69
#define GYOR_YOUT_L			0x46		// 70
#define GYOR_ZOUT_H			0x47		// 71
#define GYOR_ZOUT_L			0x48		// 72
#define SIGNAL_PATH_RESET	0x68		// 104
#define USER_CTRL			0x6A		// 106
#define PWR_MGMT_1			0x6B		// 107		reset value == 0x40
#define PWR_MGMT_2			0x6C		// 108
#define FIFO_COUNT_H		0x72		// 114
#define FIFO_COUNT_L		0x73		// 115
#define FIFO_R_W			0x74		// 116
#define WHO_AM_I			0x75		// 117		reset value == 0x68


#define RAW_COMPASS			0x49
#define YG_OFFS_TC			0x01
#define S0_ADDR				0x25
#define S0_REG				0x26
#define S0_CTRL				0x27
#define S1_ADDR				0x28
#define S1_REG				0x29
#define S1_CTRL				0x2A
#define S4_CTRL				0x34
#define S0_DO				0x63
#define S1_DO				0x64
#define I2C_MST_DELAY_CTRL	0x67

#define AKM_REG_WHOAMI		0x00

#define AKM_REG_ST1			0x02
#define AKM_REG_HXL			0x03
#define AKM_REG_ST2			0x09

#define AKM_REG_CNTL		0x0A
#define AKM_REG_ASTC		0x0C
#define AKM_REG_ASAX		0x10
#define AKM_REG_ASAY		0x11
#define AKM_REG_ASAZ		0x12

#define AKM_DATA_READY		0x01
#define AKM_DATA_OVERRUN	0x02
#define AKM_OVERFLOW		0x80
#define AKM_DATA_ERROR		0x40

#define AKM_BIT_SELF_TEST	0x40

#define SUPPORTS_AK89xx_HIGH_SENS	0x00
#define AK89xx_FSR					9830

#define AKM_POWER_DOWN				(0x00 | SUPPORTS_AK89xx_HIGH_SENS)
#define AKM_SINGLE_MEASUREMENT		(0x01 | SUPPORTS_AK89xx_HIGH_SENS)
#define AKM_FUSE_ROM_ACCESS			(0x0F | SUPPORTS_AK89xx_HIGH_SENS)
#define AKM_MODE_SELF_TEST			(0x08 | SUPPORTS_AK89xx_HIGH_SENS)

#define AKM_WHOAMI			0x48


#define INV_X_GYRO		0x40
#define INV_Y_GYRO		0x20
#define INV_Z_GYRO		0x10
#define INV_XYZ_GYRO	(INV_X_GYRO | INV_Y_GYRO | INV_Z_GYRO)
#define INV_XYZ_ACCEL	0x08
#define INV_XYZ_COMPASS	0x01


// These are not mentioned in the register map PDF,
// but you can find them in the motion driver source.
#define ACCEL_OFFS			0x06		// 6
#define BANK_SEL			0x6D		// 109
#define MEM_START_ADDR		0x6E		// 110
#define MEM_R_W				0x6F		// 111
#define PRGM_START_H		0x70		// 112
#define PRGM_START_L		0x71		// 113 this one's implied


// These defines are copied from dmpDefaultMPU6050.c in the general MPL
// releases. These defines may change for each DMP image, so be sure to modify
// these values when switching to a new image.
 
#define CFG_LP_QUAT             (2712)
#define END_ORIENT_TEMP         (1866)
#define CFG_27                  (2742)
#define CFG_20                  (2224)
#define CFG_23                  (2745)
#define CFG_FIFO_ON_EVENT       (2690)
#define END_PREDICTION_UPDATE   (1761)
#define CGNOTICE_INTR           (2620)
#define X_GRT_Y_TMP             (1358)
#define CFG_DR_INT              (1029)
#define CFG_AUTH                (1035)
#define UPDATE_PROP_ROT         (1835)
#define END_COMPARE_Y_X_TMP2    (1455)
#define SKIP_X_GRT_Y_TMP        (1359)
#define SKIP_END_COMPARE        (1435)
#define FCFG_3                  (1088)
#define FCFG_2                  (1066)
#define FCFG_1                  (1062)
#define END_COMPARE_Y_X_TMP3    (1434)
#define FCFG_7                  (1073)
#define FCFG_6                  (1106)
#define FLAT_STATE_END          (1713)
#define SWING_END_4             (1616)
#define SWING_END_2             (1565)
#define SWING_END_3             (1587)
#define SWING_END_1             (1550)
#define CFG_8                   (2718)
#define CFG_15                  (2727)
#define CFG_16                  (2746)
#define CFG_EXT_GYRO_BIAS       (1189)
#define END_COMPARE_Y_X_TMP     (1407)
#define DO_NOT_UPDATE_PROP_ROT  (1839)
#define CFG_7                   (1205)
#define FLAT_STATE_END_TEMP     (1683)
#define END_COMPARE_Y_X         (1484)
#define SKIP_SWING_END_1        (1551)
#define SKIP_SWING_END_3        (1588)
#define SKIP_SWING_END_2        (1566)
#define TILTG75_START           (1672)
#define CFG_6                   (2753)
#define TILTL75_END             (1669)
#define END_ORIENT              (1884)
#define CFG_FLICK_IN            (2573)
#define TILTL75_START           (1643)
#define CFG_MOTION_BIAS         (1208)
#define X_GRT_Y                 (1408)
#define TEMPLABEL               (2324)
#define CFG_ANDROID_ORIENT_INT  (1853)
#define CFG_GYRO_RAW_DATA       (2722)
#define X_GRT_Y_TMP2            (1379)

#define D_0_22                  (22+512)
#define D_0_24                  (24+512)

#define D_0_36                  (36)
#define D_0_52                  (52)
#define D_0_96                  (96)
#define D_0_104                 (104)
#define D_0_108                 (108)
#define D_0_163                 (163)
#define D_0_188                 (188)
#define D_0_192                 (192)
#define D_0_224                 (224)
#define D_0_228                 (228)
#define D_0_232                 (232)
#define D_0_236                 (236)
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

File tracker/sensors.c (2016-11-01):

#include <stdio.h>
#include <stdio.h>
#include <stdint.h>
#include <stdbool.h>
#include <string.h>

#include <reg24le1.h>
#include <nrfutils.h>

#include "i2c.h"
#include "tracker.h"
#include "sensor_regs.h"
#include "sensors.h"
#include "sensor_dmp_firmware.h"
#include "rf_protocol.h"
#include "tracker_settings.h"
#include "nrfdbg.h"

// This library configures the MPU chips in DMP mode and it reads the temperature and compass
// data separately.
// It also handles the HMC5883L and reads the compass data if that sensor is present instead
// of the AK8975A (which is a part of MPU-9150)

enum mag_type_e
{
	mt_none,
	mt_ak,		// AK8975A
	mt_hmc,		// HMC5883L
};

uint8_t mag_type = mt_none;
int16_t mag_sens_adj[3];

bool mpu_write_byte(uint8_t reg_addr, uint8_t val)
{
	return i2c_write(MPU_ADDR, reg_addr, 1, &val);
}

bool mpu_read_byte(uint8_t reg_addr, uint8_t* val)
{
	return i2c_read(MPU_ADDR, reg_addr, 1, val);
}

bool mpu_read_array(uint8_t reg_addr, uint8_t bytes, uint8_t* val)
{
	return i2c_read(MPU_ADDR, reg_addr, bytes, val);
}

bool mpu_write_array(uint8_t reg_addr, uint8_t bytes, const uint8_t* val)
{
	return i2c_write(MPU_ADDR, reg_addr, bytes, val);
}

bool ak_write_byte(uint8_t reg_addr, uint8_t val)
{
	return i2c_write(AK8975A_ADDR, reg_addr, 1, &val);
}

bool ak_read_byte(uint8_t reg_addr, uint8_t* val)
{
	return i2c_read(AK8975A_ADDR, reg_addr, 1, val);
}

bool ak_read_array(uint8_t reg_addr, uint8_t cnt, uint8_t* val)
{
	return i2c_read(AK8975A_ADDR, reg_addr, cnt, val);
}

bool hmc_read_array(uint8_t reg_addr, uint8_t cnt, uint8_t* val)
{
	return i2c_read(HMC5883L_ADDR, reg_addr, cnt, val);
}

// *************************************************************

bool mpu_write_mem(uint16_t mem_addr, uint16_t length, const uint8_t* data2write)
{
	uint8_t tmp[2];

	// swap bytes
	tmp[0] = (uint8_t)(mem_addr >> 8);
	tmp[1] = (uint8_t)(mem_addr & 0xFF);

	if (!mpu_write_array(BANK_SEL, 2, tmp))
		return false;

	if (!mpu_write_array(MEM_R_W, length, data2write))
		return false;

	return true;
}

bool mpu_read_mem(uint16_t mem_addr, uint16_t length, uint8_t* data2read)
{
	uint8_t tmp[2];

	tmp[0] = (uint8_t)(mem_addr >> 8);
	tmp[1] = (uint8_t)(mem_addr & 0xFF);

	if (!mpu_write_array(BANK_SEL, 2, tmp))
		return false;

	if (!mpu_read_array(MEM_R_W, length, data2read))
		return false;

	return true;
}

// **************************************************************************************

bool dmp_load_firmware(void)
{
#define LOAD_CHUNK		16
#define START_ADDR		0x0400
#define MAX_RETRY		5

	uint16_t ii, this_write;

	uint8_t cur[LOAD_CHUNK], tmp[2];

	for (ii = 0; ii < DMP_CODE_SIZE; ii += this_write)
	{
		this_write = DMP_CODE_SIZE - ii;
		if (this_write > LOAD_CHUNK)
			this_write = LOAD_CHUNK;

		if (!mpu_write_mem(ii, this_write, dmp_memory + ii))
		{
			dputs("write failed");
			return false;
		}

		if (!mpu_read_mem(ii, this_write, cur))
		{
			dputs("read failed");
			return false;
		}

		if (memcmp(dmp_memory + ii, cur, this_write))
		{
			dputs("verify failed");
			return false;
		}
	}

	// Set program start address.
	tmp[0] = START_ADDR >> 8;
	tmp[1] = START_ADDR & 0xFF;
	if (!mpu_write_array(PRGM_START_H, 2, tmp))
	{
		dputs("PRGM_START_H failed");
		return false;
	}

	return true;
}

bool dmp_set_orientation(void)
{
	const uint8_t __code arr1[3] = {0xCD, 0x4C, 0x6C};
	const uint8_t __code arr2[3] = {0xC9, 0x0C, 0x2C};
	const uint8_t __code arr3[3] = {0x36, 0x57, 0x76};
	const uint8_t __code arr4[3] = {0x26, 0x47, 0x66};

	return mpu_write_mem(FCFG_1, 3, arr1)
			&& mpu_write_mem(FCFG_2, 3, arr2)
			&& mpu_write_mem(FCFG_3, 3, arr3)
			&& mpu_write_mem(FCFG_7, 3, arr4);
}

void mpu_set_gyro_bias(const int16_t* gyro_bias)
{
	uint8_t d[2], i;

	for (i = 0; i < 3; i++)
	{
		d[0] = (gyro_bias[i] >> 8) & 0xff;
		d[1] = (gyro_bias[i]) & 0xff;
		mpu_write_array(0x13 + 2 * i, 2, d);
	}
}

void mpu_read_accel_bias(int16_t* accel_bias)
{
	uint8_t d[2], i;

	for (i = 0; i < 3; i++)
	{
		mpu_read_array(0x06 + i * 2, 2, d);
		accel_bias[i] = (d[0] << 8) | d[1];
	}
}

void mpu_set_accel_bias(const int16_t* accel_bias)
{
	uint8_t i;
	uint8_t data[2];

	// Bit 0 of the 2 byte bias is for temp comp
	// calculations need to compensate for this and not change it
	//
	// Unlike the eMPL library, we achieve this by only incrementing/decrementing the
	// accel bias with even values, thus preserving the parity of the bias and the least
	// significant bit.
	//
	// However, it looks like MPU is temperature dependant, and doesn't do compensation
	// regardless of the value of the last bit...
	for (i = 0; i < 3; i++)
	{
		data[0] = (accel_bias[i] >> 8) & 0xff;
		data[1] = accel_bias[i] & 0xff;

		mpu_write_array(0x06 + i * 2, 2, data);
	}
}

void dmp_enable_feature(void)
{
	// it would be interesting to see what would happen if I incorporated these values directly
	// into the DMP firmware image, and not write them after the image is already uploaded.

	{
	const uint8_t __code arr[] = {0x02,0xca,0xe3,0x09};
	mpu_write_mem(D_0_104, sizeof arr, arr);
	}

	{
	const uint8_t __code arr[] = {0xa3,0xc0,0xc8,0xc2,0xc4,0xcc,0xc6,0xa3,0xa3,0xa3};
	mpu_write_mem(CFG_15, sizeof arr, arr);
	}

	{	// tap is off
	const uint8_t __code arr[] = {0xd8};
	mpu_write_mem(CFG_27, sizeof arr, arr);
	}

	{
	const uint8_t __code arr[] = {0xb8,0xaa,0xb3,0x8d,0xb4,0x98,0x0d,0x35,0x5d};	// dmp_enable_gyro_cal(1)
	//const uint8_t __code arr[] = {0xb8,0xaa,0xaa,0xaa,0xb0,0x88,0xc3,0xc5,0xc7};	// dmp_enable_gyro_cal(0)
	mpu_write_mem(CFG_MOTION_BIAS, sizeof arr, arr);
	}

	{
	const uint8_t __code arr[] = {0xB0,0x80,0xB4,0x90};		// DMP_FEATURE_SEND_RAW_GYRO
	mpu_write_mem(CFG_GYRO_RAW_DATA, sizeof arr, arr);
	}

	{
	const uint8_t __code arr[] = {0xf8};
	mpu_write_mem(CFG_20, sizeof arr, arr);
	}

	{
	const uint8_t __code arr[] = {0xd8};
	mpu_write_mem(CFG_ANDROID_ORIENT_INT, sizeof arr, arr);
	}
	{
	const uint8_t __code arr[] = {0x8b,0x8b,0x8b,0x8b};
	mpu_write_mem(CFG_LP_QUAT, sizeof arr, arr);
	}
	{
	const uint8_t __code arr[] = {0x20,0x28,0x30,0x38};
	mpu_write_mem(CFG_8, sizeof arr, arr);
	}

	// this is dmp_set_fifo_rate()
	// the 0x03 is the divider of the 200 Hz DMS sample rate
	{
	const uint8_t __code arr[] = {0x00,0x03};
	mpu_write_mem(D_0_22, sizeof arr, arr);
	}
	{
	const uint8_t __code arr[] = {0xfe,0xf2,0xab,0xc4,0xaa,0xf1,0xdf,0xdf,0xbb,0xaf,0xdf,0xdf};
	mpu_write_mem(CFG_6, sizeof arr, arr);
	}
}

void mpu_set_bypass(uint8_t bypass)
{
	uint8_t byte, pin_cfg;

	mpu_read_byte(USER_CTRL, &byte);

	if (bypass)
	{
		byte &= ~BIT_I2C_MST_EN;
		pin_cfg = BIT_I2C_BYPASS_EN | BIT_INT_LEVEL;
	} else {
		byte |= BIT_I2C_MST_EN;
		pin_cfg = BIT_INT_LEVEL;
	}

	mpu_write_byte(USER_CTRL, byte);

	delay_ms(3);

	mpu_write_byte(INT_PIN_CFG, pin_cfg);
}

// data sizes
#define TEMP_DATA_SIZE		2
#define COMPASS_DATA_SIZE	8
#define QUAT_DATA_SIZE		16
#define ACCEL_DATA_SIZE		6
#define GYRO_DATA_SIZE		6

#define FIFO_BUFFER_CAPACITY	(QUAT_DATA_SIZE + ACCEL_DATA_SIZE + GYRO_DATA_SIZE)
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

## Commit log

2016-11-01 the first mouse buttons
2016-11-01 kbd_module diode correction
    [kbd_module.kicad_pcb]
2016-11-02 dual diodes
    [kbd_module.kicad_pcb, kbd_module.sch]
2016-11-06 moved the diodes from the edge
    [kbd_module.kicad_pcb]
2016-11-11 removed mouse buttons from the dongle code
2016-11-13 moved the buttons to the joystick report
2016-12-06 fixed the DBG_MODE and KBD_MODULE bug
    [tracker.c]
